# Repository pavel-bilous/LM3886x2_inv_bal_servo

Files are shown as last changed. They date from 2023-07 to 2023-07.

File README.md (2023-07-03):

# LM3886x2_inv_bal_servo

## Schematics:

Two paralleled LM3886 are used to double the current drive and to increase the power output. Safe voltage to power the amplifier is 36V.
Gain is set to 11 V/V. Benefits of using two chips in parallel include: increase of the output drive capability of an amplifier, reduced voltage noise (better SNR), and reduced output offset error.

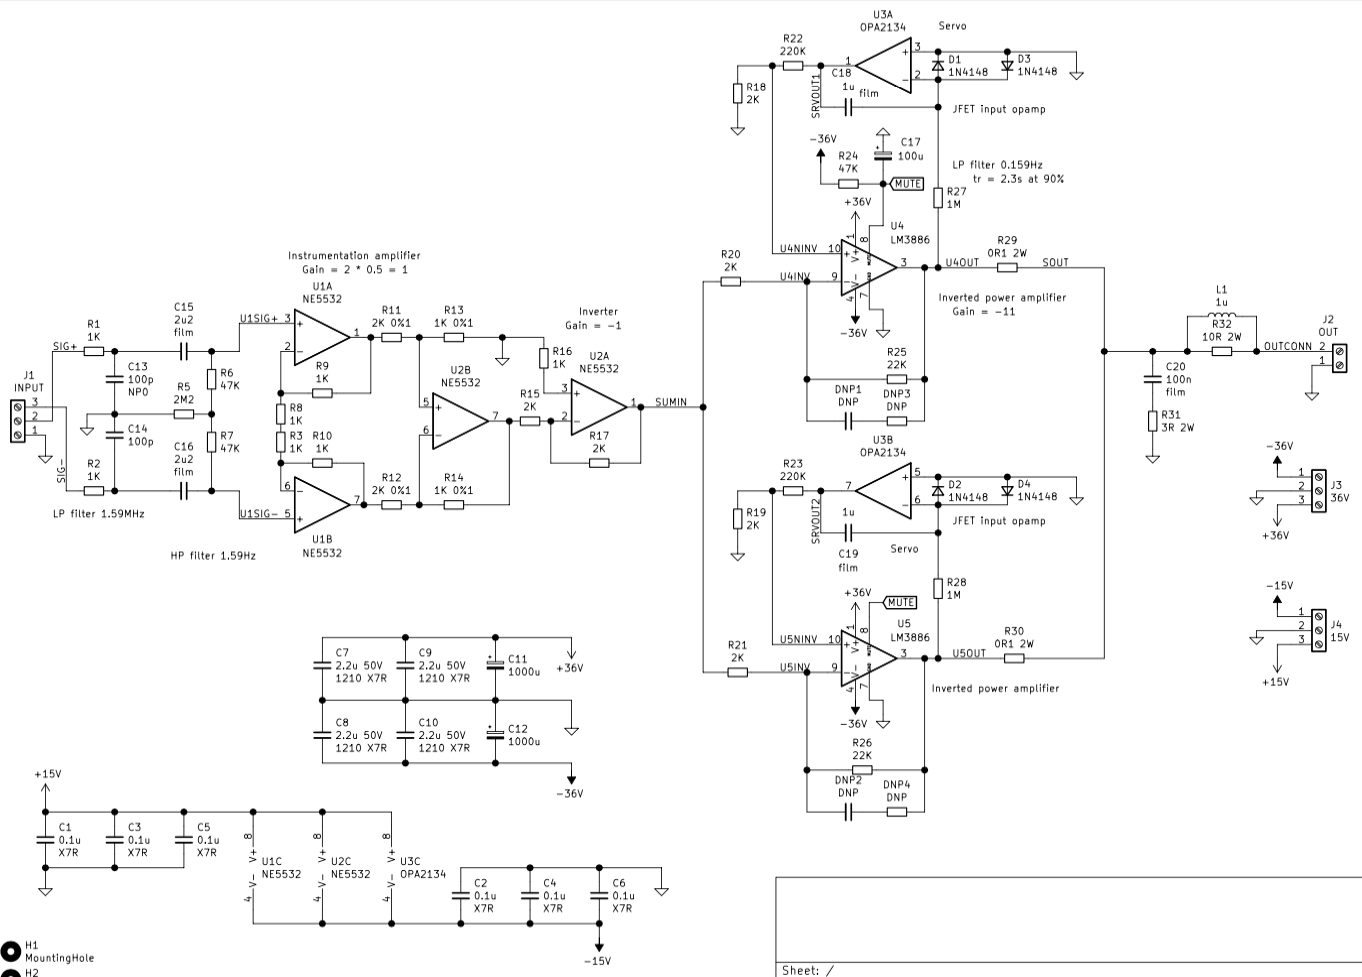
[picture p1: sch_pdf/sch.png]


## PCB rendered in 3d:
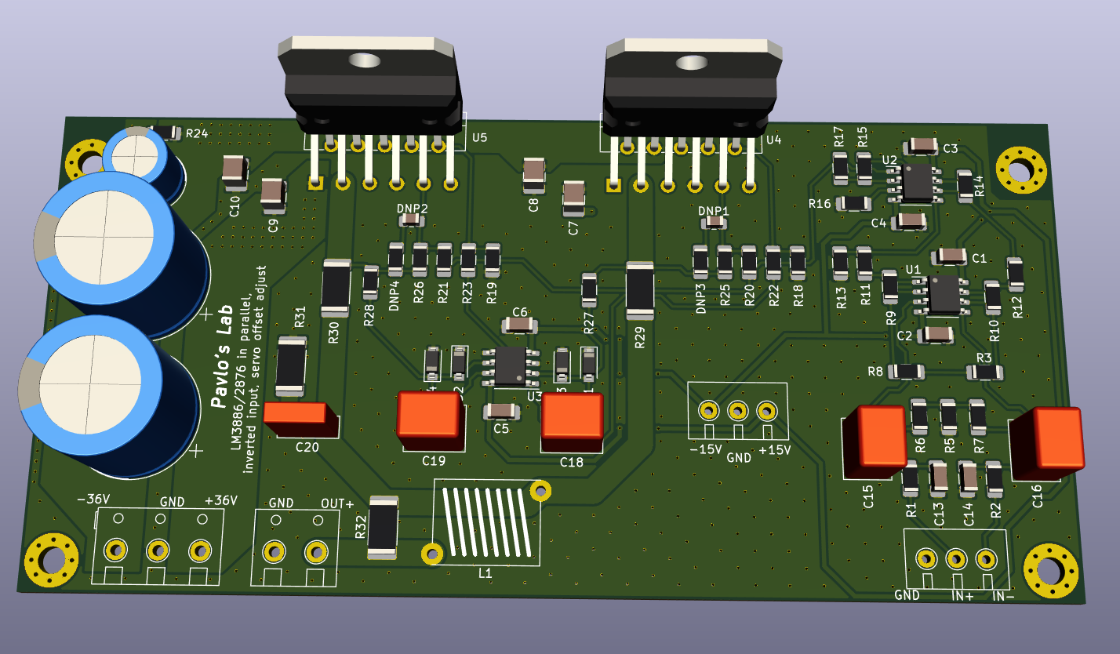
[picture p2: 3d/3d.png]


## PCB layout:

Bottom layer is GND. Top layer is signal + power and GND poured in between. Stiching vias are then applied to connect bottom and top GND planes to ensure those are as close to 0 as possible.

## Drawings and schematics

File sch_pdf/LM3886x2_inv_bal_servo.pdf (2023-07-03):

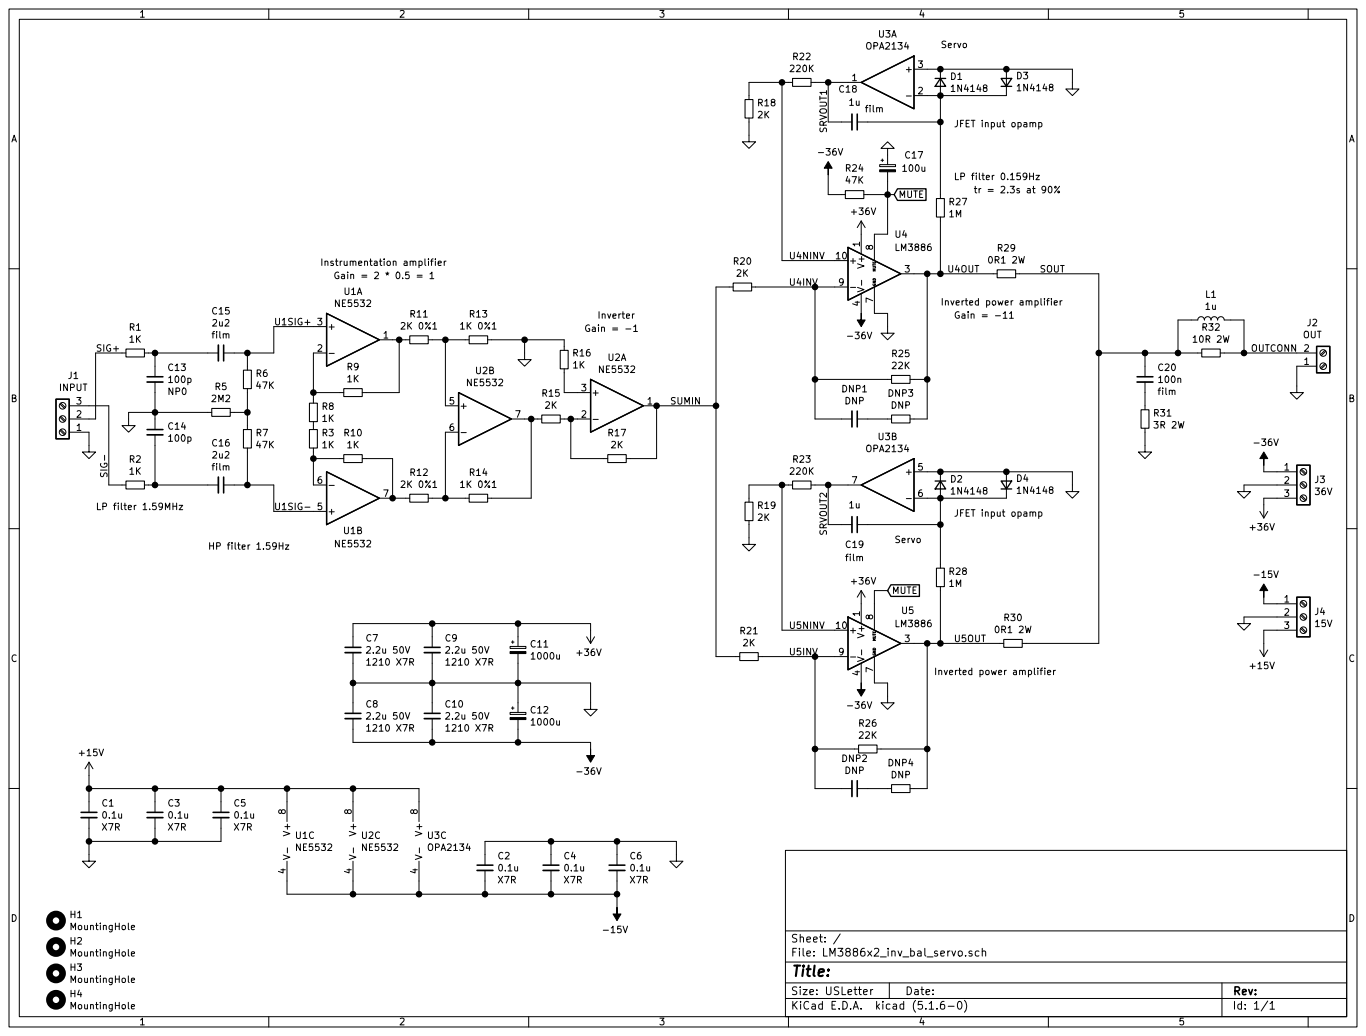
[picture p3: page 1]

Inverted power amplifier LP filter 0.159Hz HP filter 1.59Hz LP filter 1.59MHz

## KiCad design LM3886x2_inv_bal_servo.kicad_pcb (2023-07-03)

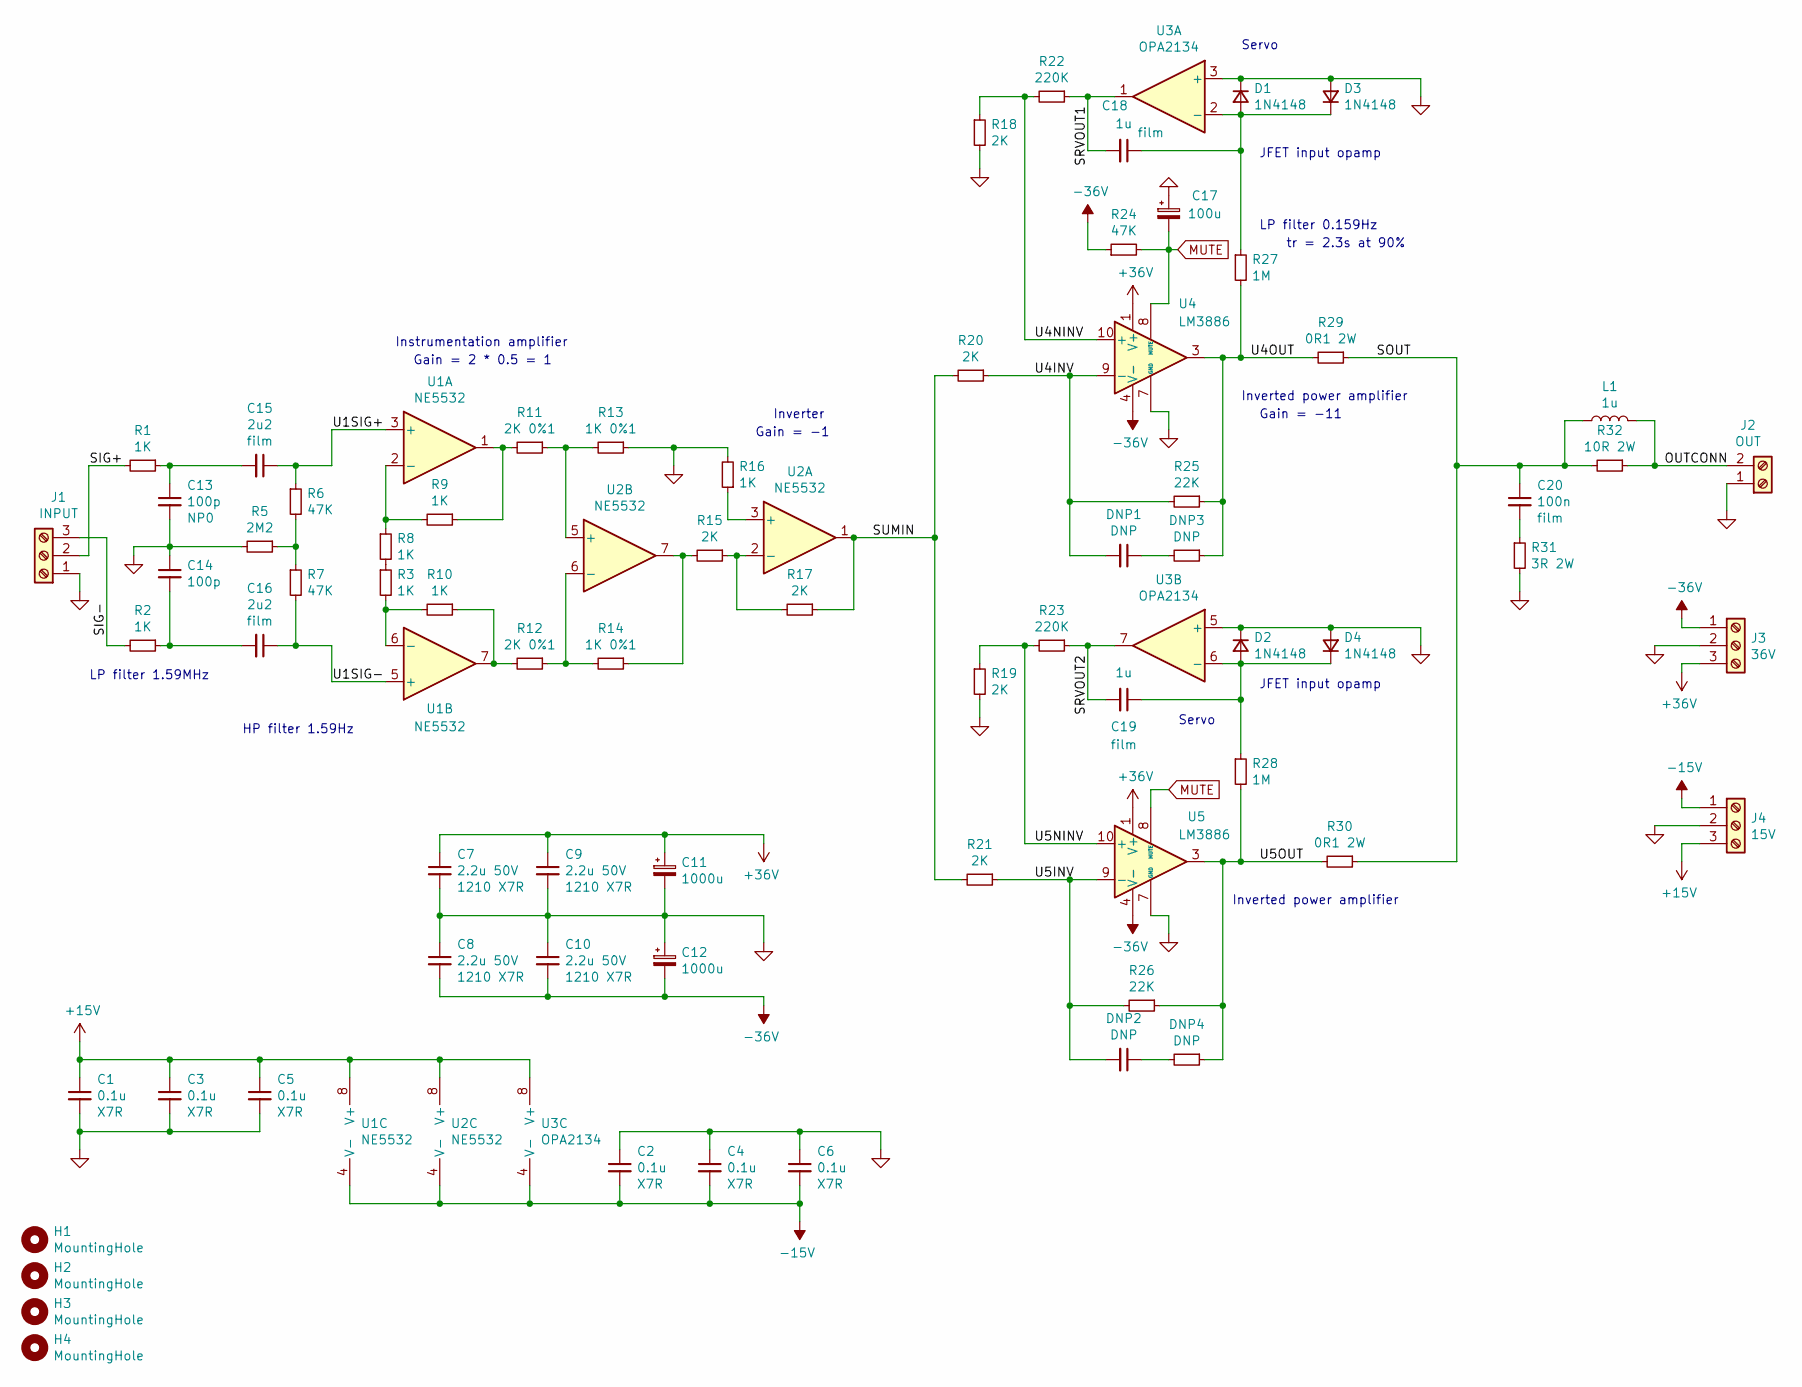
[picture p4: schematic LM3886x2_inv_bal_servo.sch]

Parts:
C1, C2, C3, C4, C5, C6: 0.1u; C_1206_3216Metric_Pad1.42x1.75mm_HandSolder
C7, C8, C9, C10: 2.2u 50V; C_1210_3225Metric_Pad1.42x2.65mm_HandSolder
C11, C12: 1000u; CP_Radial_D16.0mm_P7.50mm
C13, C14: 100p; C_1206_3216Metric_Pad1.42x1.75mm_HandSolder
C15, C16: 2u2; C_Rect_L7.2mm_W5.5mm_P5.00mm_FKS2_FKP2_MKS2_MKP2
C17: 100u; CP_Radial_D8.0mm_P3.80mm
C18, C19: 1u; C_Rect_L7.2mm_W5.5mm_P5.00mm_FKS2_FKP2_MKS2_MKP2
C20: 100n; C_Rect_L7.2mm_W2.5mm_P5.00mm_FKS2_FKP2_MKS2_MKP2
D1, D2, D3, D4: 1N4148; D_SOD-123
DNP1, DNP2: DNP; C_0805_2012Metric_Pad1.15x1.40mm_HandSolder
DNP3, DNP4: DNP; R_1206_3216Metric_Pad1.42x1.75mm_HandSolder
H1, H2, H3, H4: MountingHole; MountingHole_3.2mm_M3_Pad_Via
J1: INPUT; TerminalBlock_ Amphenol_01_03_P3.50mm
J2: OUT; TerminalBlock_CUI_01x02_P5.00mm
J3: 36V; TerminalBlock_CUI_01x03_P5.00mm
J4: 15V; TerminalBlock_ Amphenol_01_03_P3.50mm
L1: 1u; Inductor_DIY
R1, R2, R3, R8, R9, R10, R16: 1K; R_1206_3216Metric_Pad1.42x1.75mm_HandSolder
R5: 2M2; R_1206_3216Metric_Pad1.42x1.75mm_HandSolder
R6, R7, R24: 47K; R_1206_3216Metric_Pad1.42x1.75mm_HandSolder
R11, R12: 2K 0%1; R_1206_3216Metric_Pad1.42x1.75mm_HandSolder
R13, R14: 1K 0%1; R_1206_3216Metric_Pad1.42x1.75mm_HandSolder
R15, R17, R18, R19, R20, R21: 2K; R_1206_3216Metric_Pad1.42x1.75mm_HandSolder
R22, R23: 220K; R_1206_3216Metric_Pad1.42x1.75mm_HandSolder
R25, R26: 22K; R_1206_3216Metric_Pad1.42x1.75mm_HandSolder
R27, R28: 1M; R_1206_3216Metric_Pad1.42x1.75mm_HandSolder
R29, R30: 0R1 2W; R_2512_6332Metric_Pad1.52x3.35mm_HandSolder
R31: 3R 2W; R_2512_6332Metric_Pad1.52x3.35mm_HandSolder
R32: 10R 2W; R_2512_6332Metric_Pad1.52x3.35mm_HandSolder
U1, U2: NE5532; SOIC-8_3.9x4.9mm_P1.27mm
U3: OPA2134; SOIC-8_3.9x4.9mm_P1.27mm
U4, U5: LM3886; TO-220-11_P3.4x5.08mm_StaggerOdd_Lead4.85mm_Vertical

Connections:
+15V: C1.1, C3.1, C5.1, J4.3, U1.8 (V+), U2.8 (V+), U3.8 (V+)
+36V: C7.1, C9.1, C11.1, J3.3, U4.1 (V+), U4.5 (V+), U5.1 (V+), U5.5 (V+)
-15V: C2.2, C4.2, C6.2, J4.1, U1.4 (V-), U2.4 (V-), U3.4 (V-)
-36V: C8.2, C10.2, C12.2, J3.1, R24.1, U4.4 (V-), U5.4 (V-)
/OUTCONN: J2.2, L1.2, R32.1
/SIG+: J1.2, R1.2
/SIG-: J1.3, R2.2
/SOUT: C20.1, L1.1, R29.1, R30.1, R32.2
/SRVOUT1: C18.2, R22.1, U3.1
/SRVOUT2: C19.2, R23.1, U3.7
/SUMIN: R17.1, R20.2, R21.2, U2.1
/U1SIG+: C15.1, R6.1, U1.3 (+)
/U1SIG-: C16.1, R7.2, U1.5 (+)
/U4INV: DNP1.2, R20.1, R25.2, U4.9 (-)
/U4NINV: R18.1, R22.2, U4.10 (+)
/U4OUT: DNP3.1, R25.1, R27.2, R29.2, U4.3
/U5INV: DNP2.2, R21.1, R26.2, U5.9 (-)
/U5NINV: R19.1, R23.2, U5.10 (+)
/U5OUT: DNP4.1, R26.1, R28.2, R30.2, U5.3
GND: C1.2, C2.1, C3.2, C4.1, C5.2, C6.1, C7.2, C8.1, C9.2, C10.1, C11.2, C12.1, C13.2, C14.1, C17.1, D1.1 (K), D2.1 (K), D3.2 (A), D4.2 (A), J1.1, J2.1, J3.2, J4.2, R5.2, R13.1, R16.2, R18.2, R19.2, R31.2, U3.3 (+), U3.5 (+), U4.7 (GND), U5.7 (GND)
MUTE: C17.2, R24.2, U4.8 (MUTE), U5.8 (MUTE)
unnamed: C13.1, C15.2, R1.1
unnamed: C14.2, C16.2, R2.1
unnamed: C18.1, D1.2 (A), D3.1 (K), R27.1, U3.2 (-)
unnamed: C19.1, D2.2 (A), D4.1 (K), R28.1, U3.6 (-)
unnamed: C20.2, R31.1
unnamed: DNP1.1, DNP3.2
unnamed: DNP2.1, DNP4.2
unnamed: R3.1, R8.2
unnamed: R5.1, R6.2, R7.1
unnamed: R8.1, R9.2, U1.2 (-)
unnamed: R10.1, R12.2, U1.7
unnamed: R3.2, R10.2, U1.6 (-)
unnamed: R11.1, R13.2, U2.5 (+)
unnamed: R9.1, R11.2, U1.1
unnamed: R12.1, R14.2, U2.6 (-)
unnamed: R14.1, R15.2, U2.7
unnamed: R15.1, R17.2, U2.2 (-)
unnamed: R16.1, U2.3 (+)

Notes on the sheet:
Instrumentation amplifier
Inverter
Servo
Inverted power amplifier
LP filter 1.59MHz
HP filter 1.59Hz
LP filter 0.159Hz
tr = 2.3s at 90%
Gain = -11
Gain = -1
Gain = 2 * 0.5 = 1
JFET input opamp

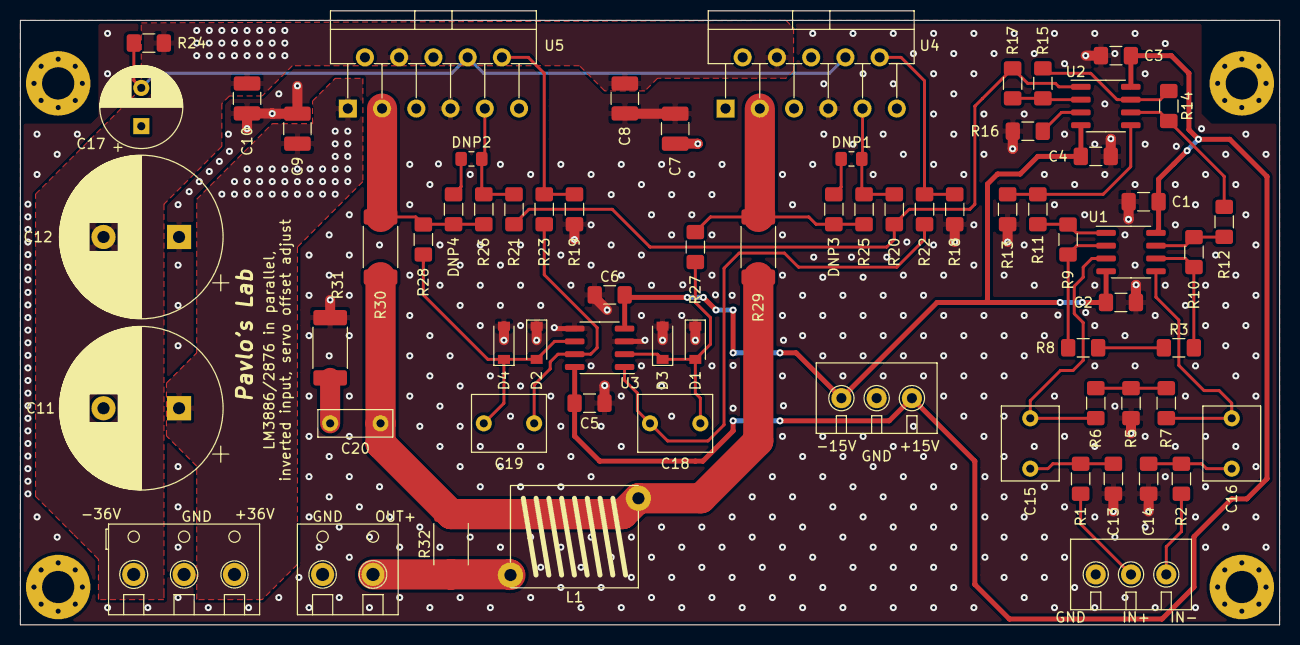
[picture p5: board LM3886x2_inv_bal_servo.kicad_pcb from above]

Board: 2 copper layers, 125.0 x 60.0 mm, 73 parts (0 on the bottom side), 39 nets.

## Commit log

2023-06-29 updated sch
    [LM3886x2_inv_bal_servo.sch]
2023-07-01 pcb is started
    [LM3886x2_inv_bal_servo.sch]
2023-07-03 finished PCB layout
    [LM3886x2_inv_bal_servo-B_Cu.gbr, LM3886x2_inv_bal_servo-B_Mask.gbr, LM3886x2_inv_bal_servo-B_Paste.gbr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]
